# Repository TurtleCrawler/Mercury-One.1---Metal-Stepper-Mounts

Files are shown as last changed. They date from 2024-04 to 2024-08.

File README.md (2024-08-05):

# Mercury One.1 - Metal Stepper Mounts
 Metal stepper mounts for the Mercury one.1

The DXF Files may change based on feedback, I have made a few minor iterations for my own testing.

 These are a self source design using laser cut aluminum plates from vendors like sendcutsend. The center printed parts are non structual. They space the flange stack bearings and have a self guiding belth path around the stepper pulley.
 
 There are two sets of files, imperial for .125 inch plate, and metric for 3mm plate.

Update August 4th 2024:
* Added 0.2mm offset files, the extra layer is added to the base after seeing up to .2mm of thickness missing in the flanges on some printers. You might need to mix and match offset and standard files. The stack height of each assembly should be 35mm tall, but no taller.
* Added a full window cutout to view the pulley and where the belt is riding along the pulley. A new printed tool has also been added. To use the tool, make sure the arrow is facing the side with the bearing stacks as you feed the belt through.

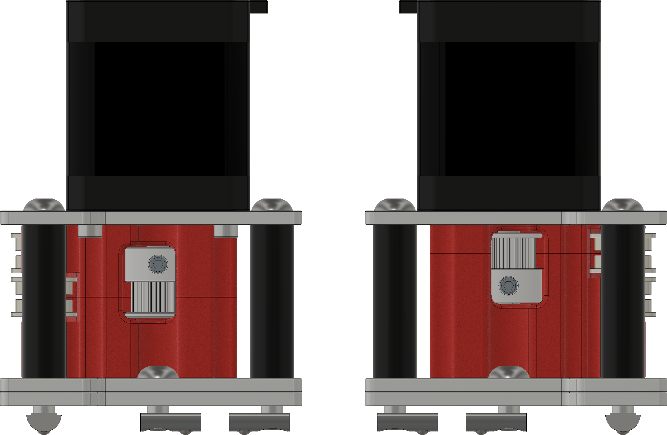
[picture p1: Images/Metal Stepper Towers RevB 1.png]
Metal Stepper Towers
 

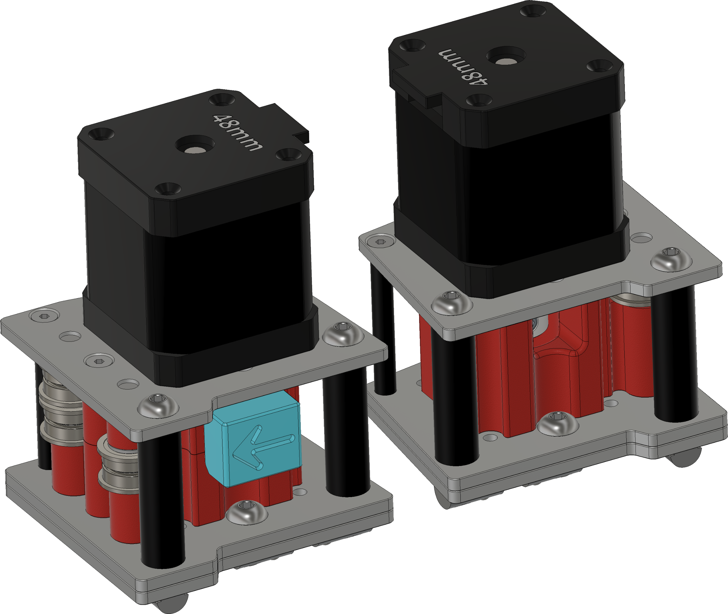
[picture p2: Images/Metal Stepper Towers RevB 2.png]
Metal Stepper Towers


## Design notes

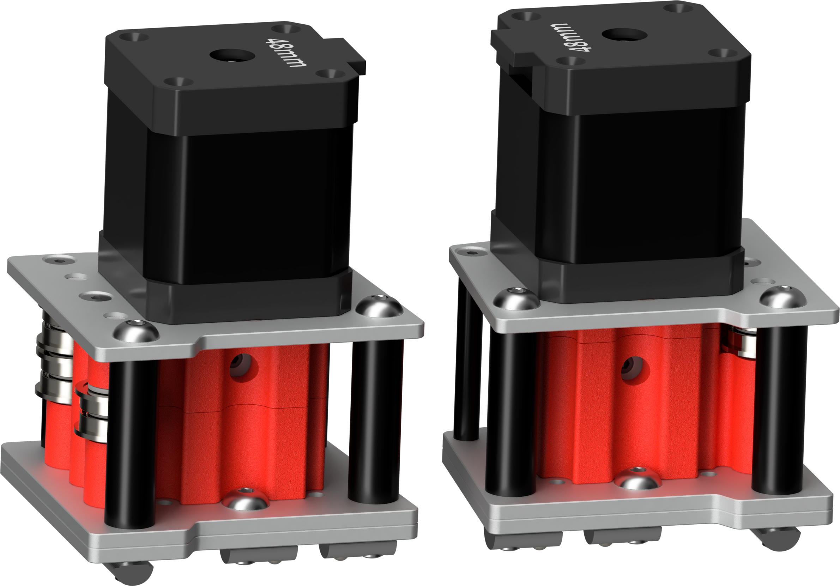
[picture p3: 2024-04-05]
Images/Metal Stepper Towers.png

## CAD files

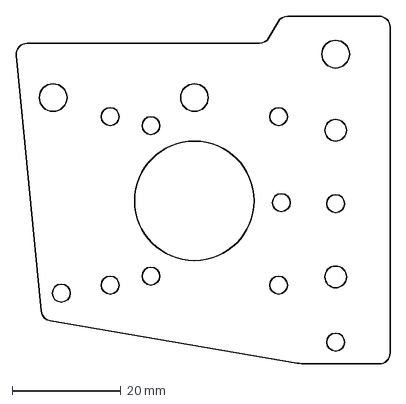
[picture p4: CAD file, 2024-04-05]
DXF Rev B/stepper bottom plate.dxf
68.8 x 64.0 mm

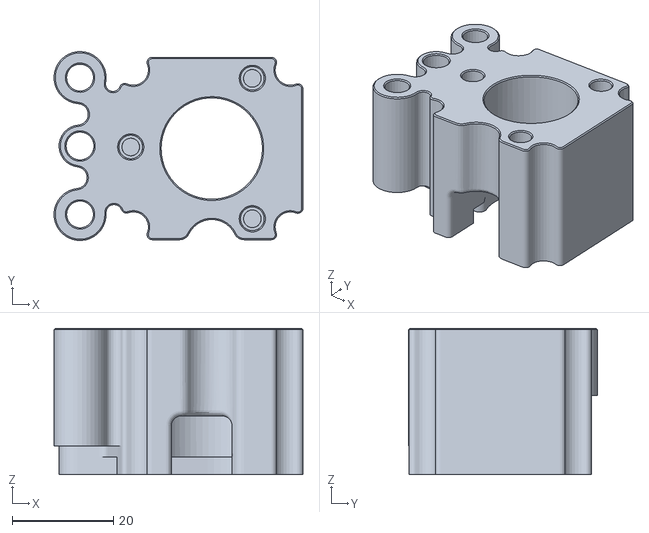
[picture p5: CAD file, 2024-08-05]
Imperial/RevB 0.2mm Offset Inserts/Printed Bottom Right Insert.stl
49.1 x 37.3 x 28.8

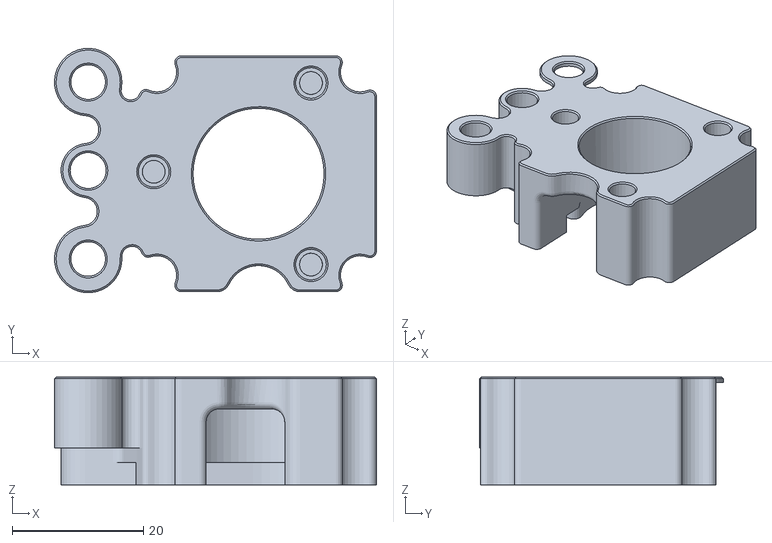
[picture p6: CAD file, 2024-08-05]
Imperial/RevB standard inserts/Printed Top Left Insert.stl
49.1 x 37.3 x 16.4

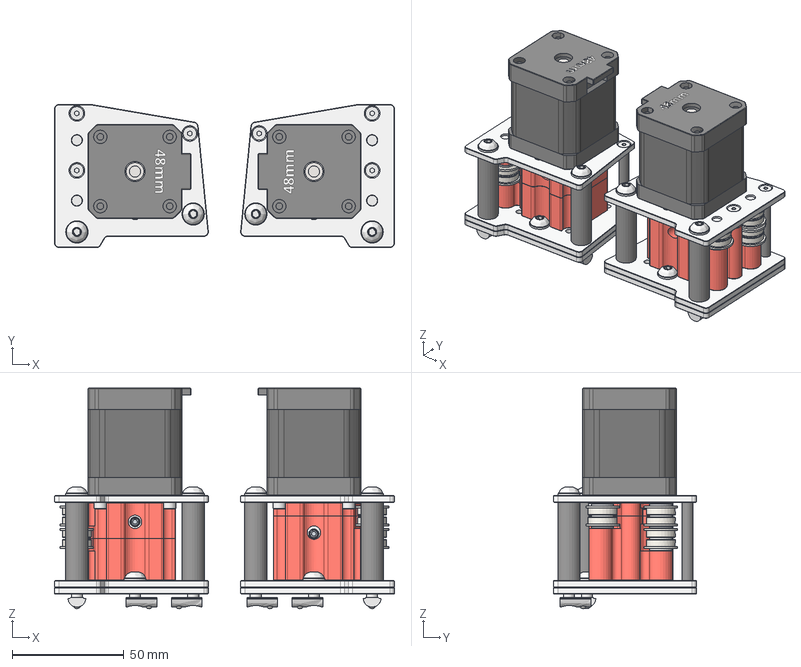
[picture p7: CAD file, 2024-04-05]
Metric/Metric Metal Stepper Towers.step
152.0 x 64.0 x 98.6 mm
Top Plate
Center Plate
Bottom Plate
Printed Top Left Insert
Printed Bottom Left Insert
M3x35 Standoff x 3
M5 Spacer x 2
SHIM x 3
F695 Bearing x 2
Pin 5 x 40 (1) x 2
SHIM (1) x 5
F695 Bearing (1) x 4
Nema 17 48mm <1> x 2
20t 2gt Pulley 5mm x 2
Hex socket set screw with cone point M4x0.7 x 4 x 4
M5x10 BHCS v1 x 2
M5x10 BHCS v1 (1) x 4
M5 Washer x 6
M5 Roll In T-Nut v2 x 6
M3 x D5 x L4 Heatset x 6
M3x8 FHCS x 12
M3x12 FHCS x 12
M3x 8 SHCS x 8
Top Plate (1)
Center Plate (1)
Bottom Plate (1)
Printed Top Right Insert
Printed Bottom Right Insert
M3x35 Standoff (1) x 3
M5x35 Spacer x 2
SHIM (1)(Mirror) x 5
F695 Bearing (1)(Mirror) x 4
Pin 5 x 40 x 2
SHIM(Mirror) x 3
F695 Bearing(Mirror) x 2
M3 x D5 x L4 Heatset(Mirror) x 6

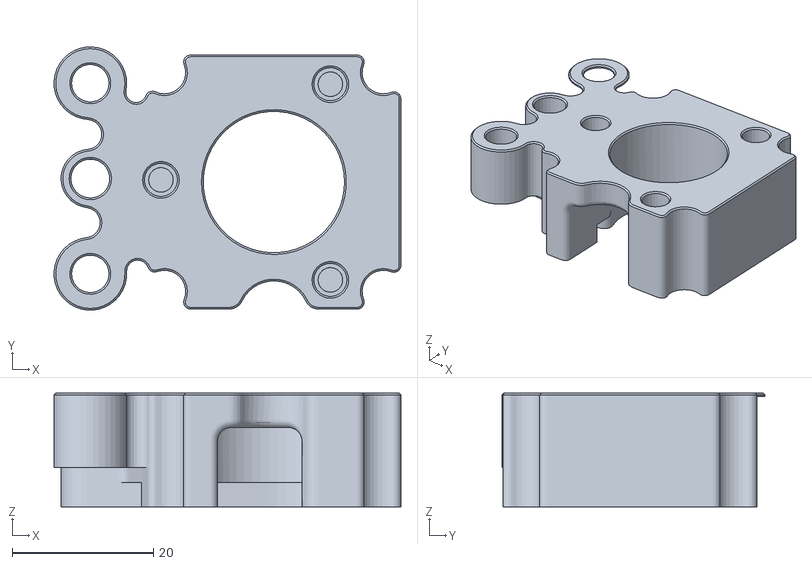
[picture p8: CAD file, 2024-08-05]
Metric/RevB standard inserts/Printed Top Left Insert.stl
49.1 x 37.3 x 16.1

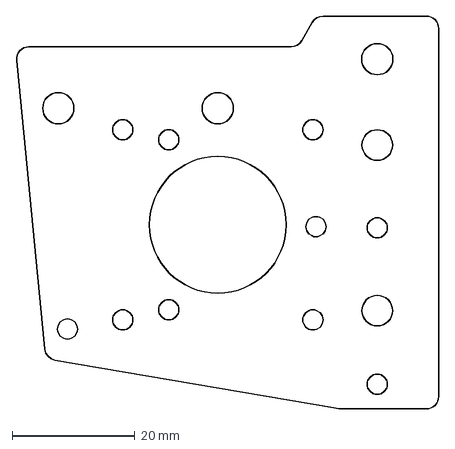
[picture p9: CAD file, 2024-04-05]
DXF Rev B/stepper top-center plate.dxf
68.8 x 64.0 mm

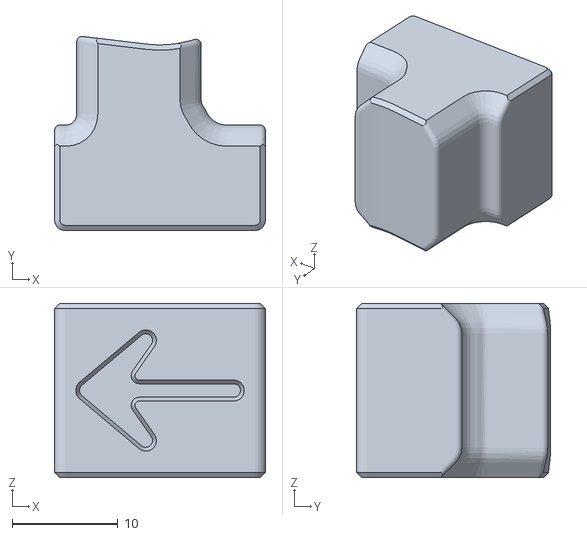
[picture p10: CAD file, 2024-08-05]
Imperial/RevB 0.2mm Offset Inserts/Belt Guide Tool.stl
20.0 x 18.4 x 16.5

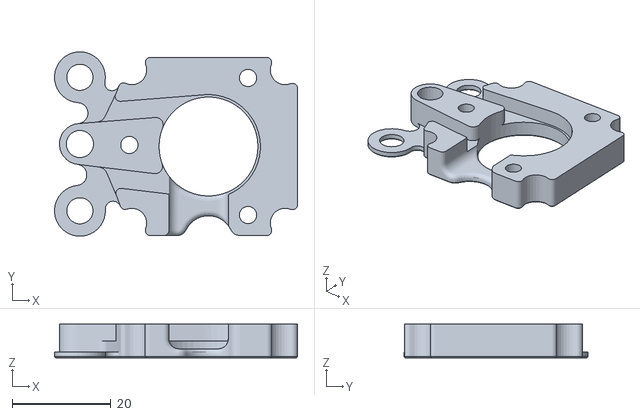
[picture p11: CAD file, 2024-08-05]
Imperial/RevB 0.2mm Offset Inserts/Printed Top Right Insert.stl
49.1 x 37.3 x 6.85

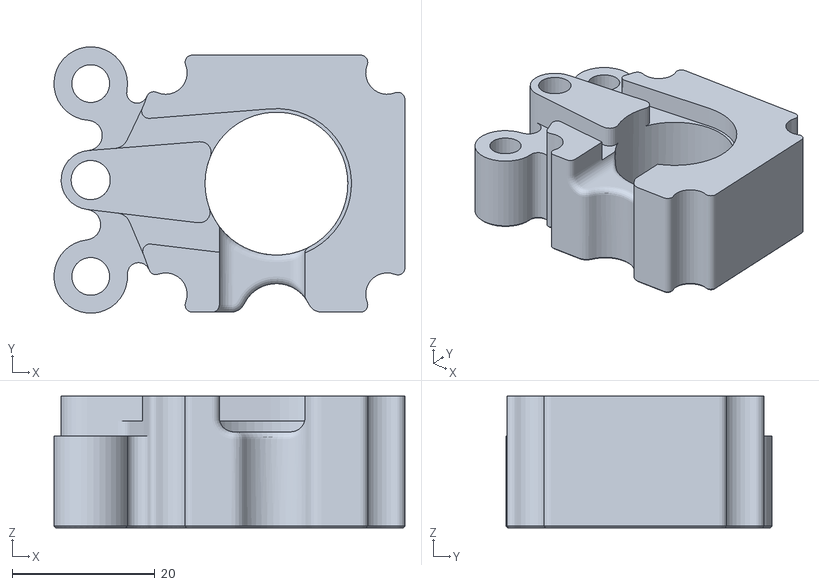
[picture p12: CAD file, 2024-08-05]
Imperial/RevB standard inserts/Printed Bottom Left Insert.stl
49.1 x 37.3 x 18.4

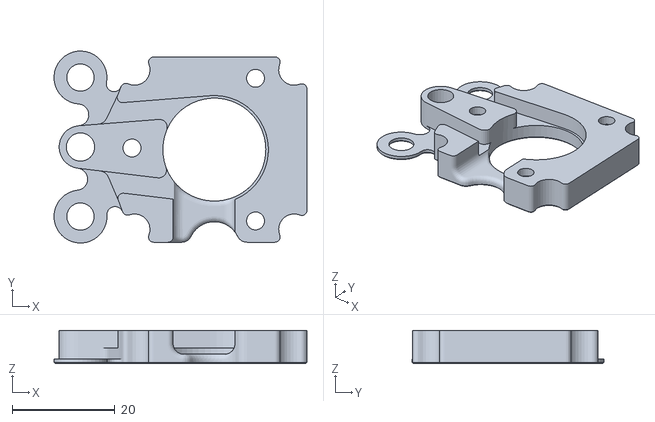
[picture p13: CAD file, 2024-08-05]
Metric/RevB 0.2mm Offset Inserts/Printed Top Right Insert.stl
49.1 x 37.3 x 6.50

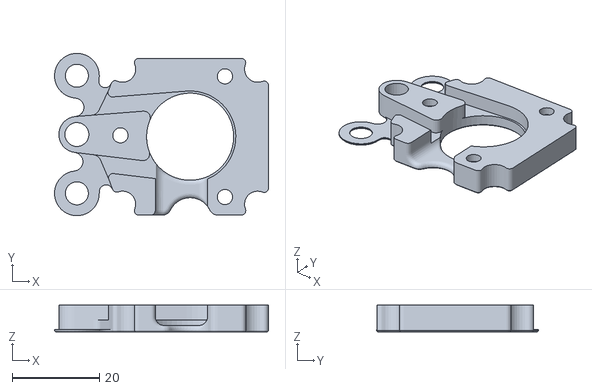
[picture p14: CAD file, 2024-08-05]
Metric/RevB standard inserts/Printed Top Right Insert.stl
49.1 x 37.3 x 6.10

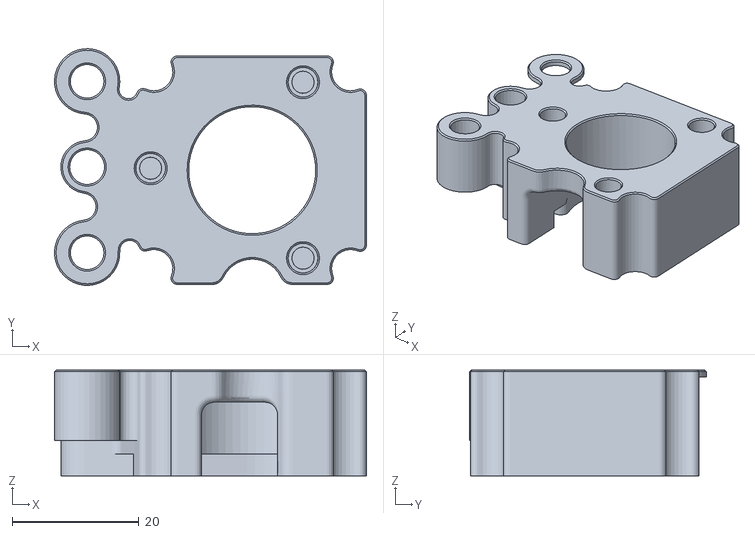
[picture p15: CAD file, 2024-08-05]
Imperial/RevB 0.2mm Offset Inserts/Printed Top Left Insert.stl
49.1 x 37.3 x 16.6

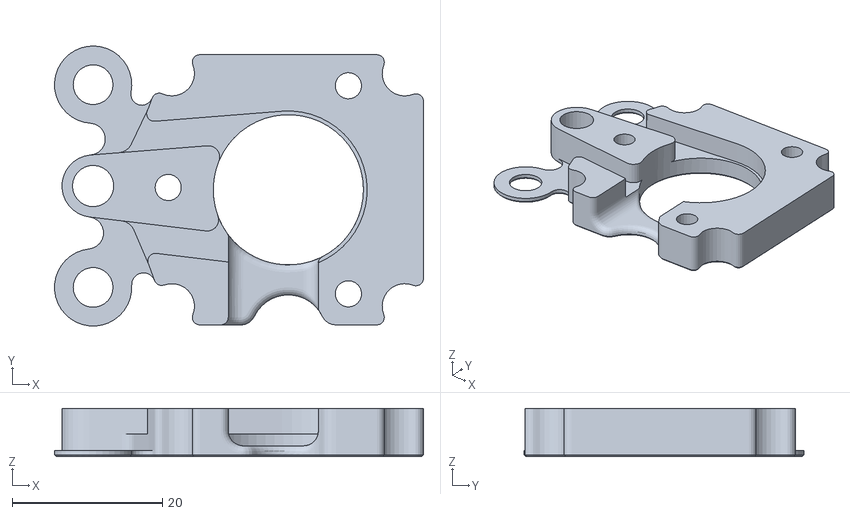
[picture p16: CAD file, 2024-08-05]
Imperial/RevB standard inserts/Printed Top Right Insert.stl
49.1 x 37.3 x 6.45

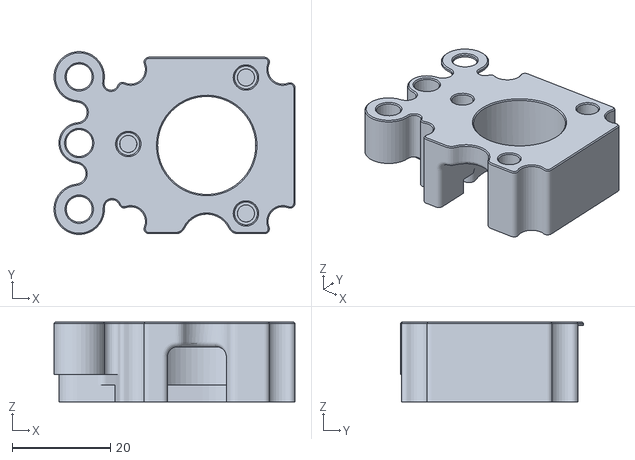
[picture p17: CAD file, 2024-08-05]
Metric/RevB 0.2mm Offset Inserts/Printed Top Left Insert.stl
49.1 x 37.3 x 16.3

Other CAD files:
Metric/RevB 0.2mm Offset Inserts/Printed Bottom Right Insert.stl
Imperial/Imperial Metal Stepper Towers.step
Imperial/Printed Bottom Left Insert.stl
Imperial/Printed Bottom Right Insert.stl
Imperial/Printed Top Left Insert.stl
Imperial/Printed Top Right Insert.stl
Imperial/RevB 0.2mm Offset Inserts/Printed Bottom Left Insert.stl
Imperial/RevB standard inserts/Printed Bottom Right Insert.stl
Metric/Printed Bottom Left Insert.stl
Metric/Printed Bottom Right Insert.stl
Metric/Printed Top Left Insert.stl
Metric/Printed Top Right Insert.stl
Metric/RevB 0.2mm Offset Inserts/Printed Bottom Left Insert.stl
Metric/RevB standard inserts/Printed Bottom Left Insert.stl
Metric/RevB standard inserts/Printed Bottom Right Insert.stl

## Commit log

2024-04-05 Push Files
    [Imperial Metal Stepper Towers.step, Metric Metal Stepper Towers.step, Printed Bottom Left Insert.stl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]
2024-04-05 Update Metal Stepper Towers.png
2024-08-05 RevB - Added front window cutout for the pulleys
    I wanted to be able to see how the belt was tracking on the pulleys, but still retain the ability to self feed the belts. So I added a tool that plugs into the window when feeding the belts.
    Also added a set of +0.2mm files to compensate for parts that print short.
    [Belt Guide Tool.stl, Printed Bottom Left Insert.stl, Printed Bottom Right Insert.stl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]
